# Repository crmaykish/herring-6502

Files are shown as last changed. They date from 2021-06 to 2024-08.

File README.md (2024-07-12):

# Herring 6502

Herring is an 8-bit computer built around the 65C02 CPU. It is designed as a backplane system. The backplane board is passive, providing only power, a reset switch, and system bus headers.
The system bus is exposed as single-row 40-pin female headers using standard 0.1 inch pin pitch.

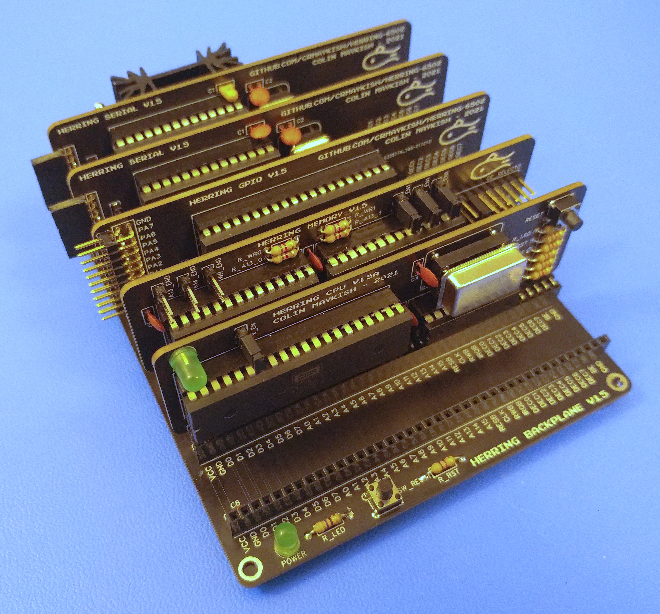
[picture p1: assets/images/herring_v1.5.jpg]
Herring 6502 v1.5


## Hardware

The memory map is set up in the following way:

1. 0x0000 - 0x7FFF: Low RAM (32K)
2. 0x8000 - 0xBFFF: Bankable RAM (16K pages)
3. 0xC000 - 0xDFFF: Memory-mapped I/O (8K)
4. 0xE000 - 0xFFFF: ROM (8K)

Individual component boards are connected to the backplane via the 40-pin system bus. Most of the pins on the bus come directly from the 65C02 plus a few for peripheral support. They are mapped from left to right in the following order:

1. VCC (5v regulated)
2. GND
3. D0
4. D1
5. D2
6. D3
7. D4
8. D5
9. D6
10. D7
11. A0
12. A1
13. A2
14. A3
15. A4
16. A5
17. A6
18. A7
19. A8
20. A9
21. A10
22. A11
23. A12
24. A13
25. A14
26. A15
27. RESB - Reset (Active low)
28. CLK - System clock
29. RWB - Read/write flag (Read = high, Write = low)
30. IRQB - Interrupt request (Active low)
31. DEC0 - Functions as the RAM write-enable pin
32. DEC1 - Peripheral enable
33. DEC2 - Peripheral enable
34. DEC3 - Peripheral enable
35. DEC4 - Peripheral enable
36. DEC5 - Peripheral enable
37. DEC6 - Peripheral enable
38. DEC7 - Peripheral enable
39. BE - Bus Enable (Active high)
40. GND

## Software

Herring currently runs a simple monitor program from ROM that provides the basic peek, poke, jump commands as well as memory clearing and memory dumping. This monitor also functions as a bootloader, allowing new firmware to be copied into RAM from a host PC via serial port. I use a simple program on the PC to transfer firmware: https://github.com/crmaykish/ctt in this way.

All firmware development is done in C and uses the cc65 set of tools.

## Further Reading

See https://hackaday.io/project/181802-herring-6502-computer for project logs and more details on the hardware.

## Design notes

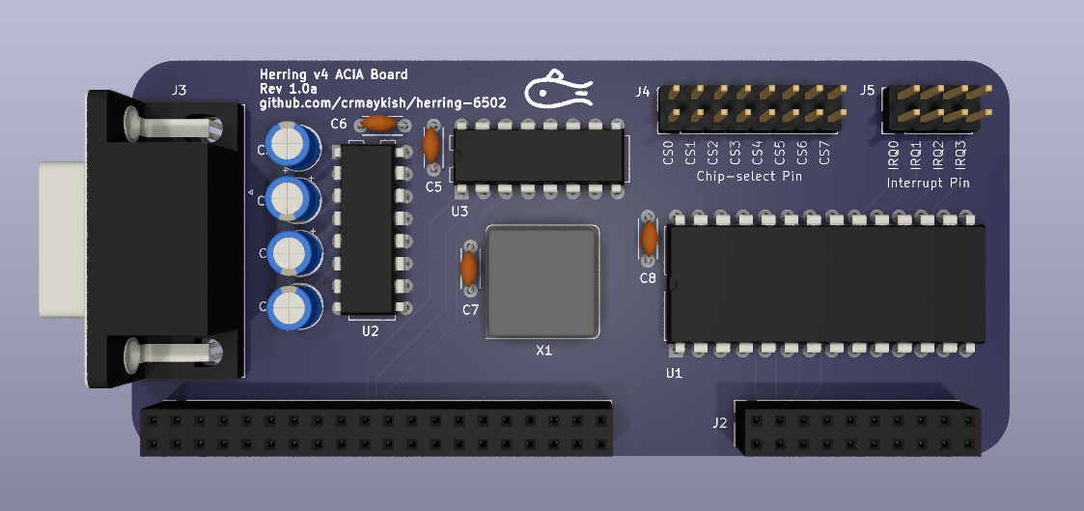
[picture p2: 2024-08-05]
assets/images/herring_v4_acia_rev1a_render.png

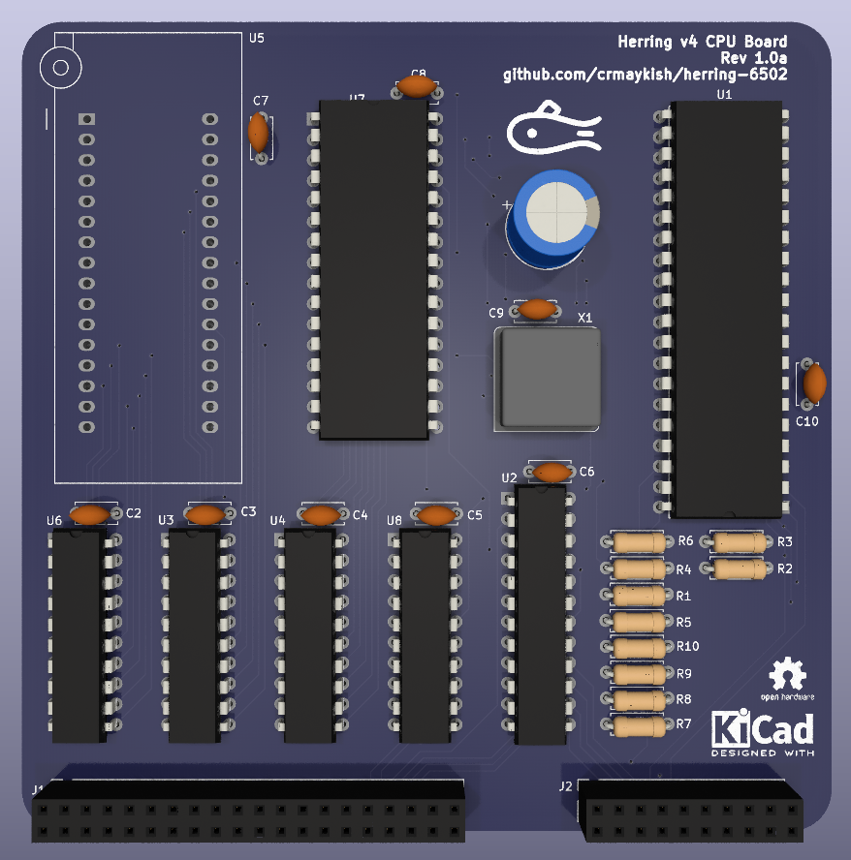
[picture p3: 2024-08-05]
assets/images/herring_v4_cpu_rev1a_render.png

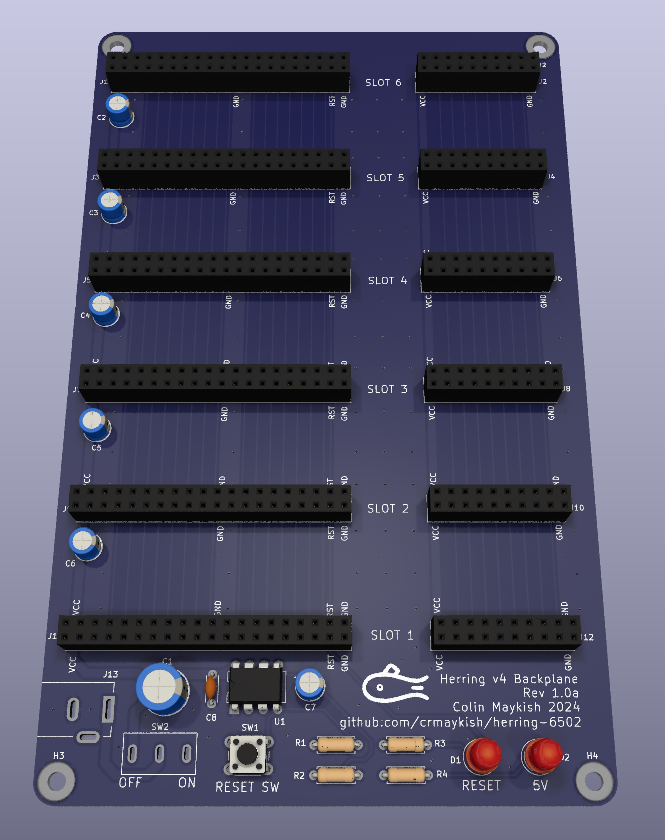
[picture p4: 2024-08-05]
assets/images/herring_v4_backplane_rev1a_render.png

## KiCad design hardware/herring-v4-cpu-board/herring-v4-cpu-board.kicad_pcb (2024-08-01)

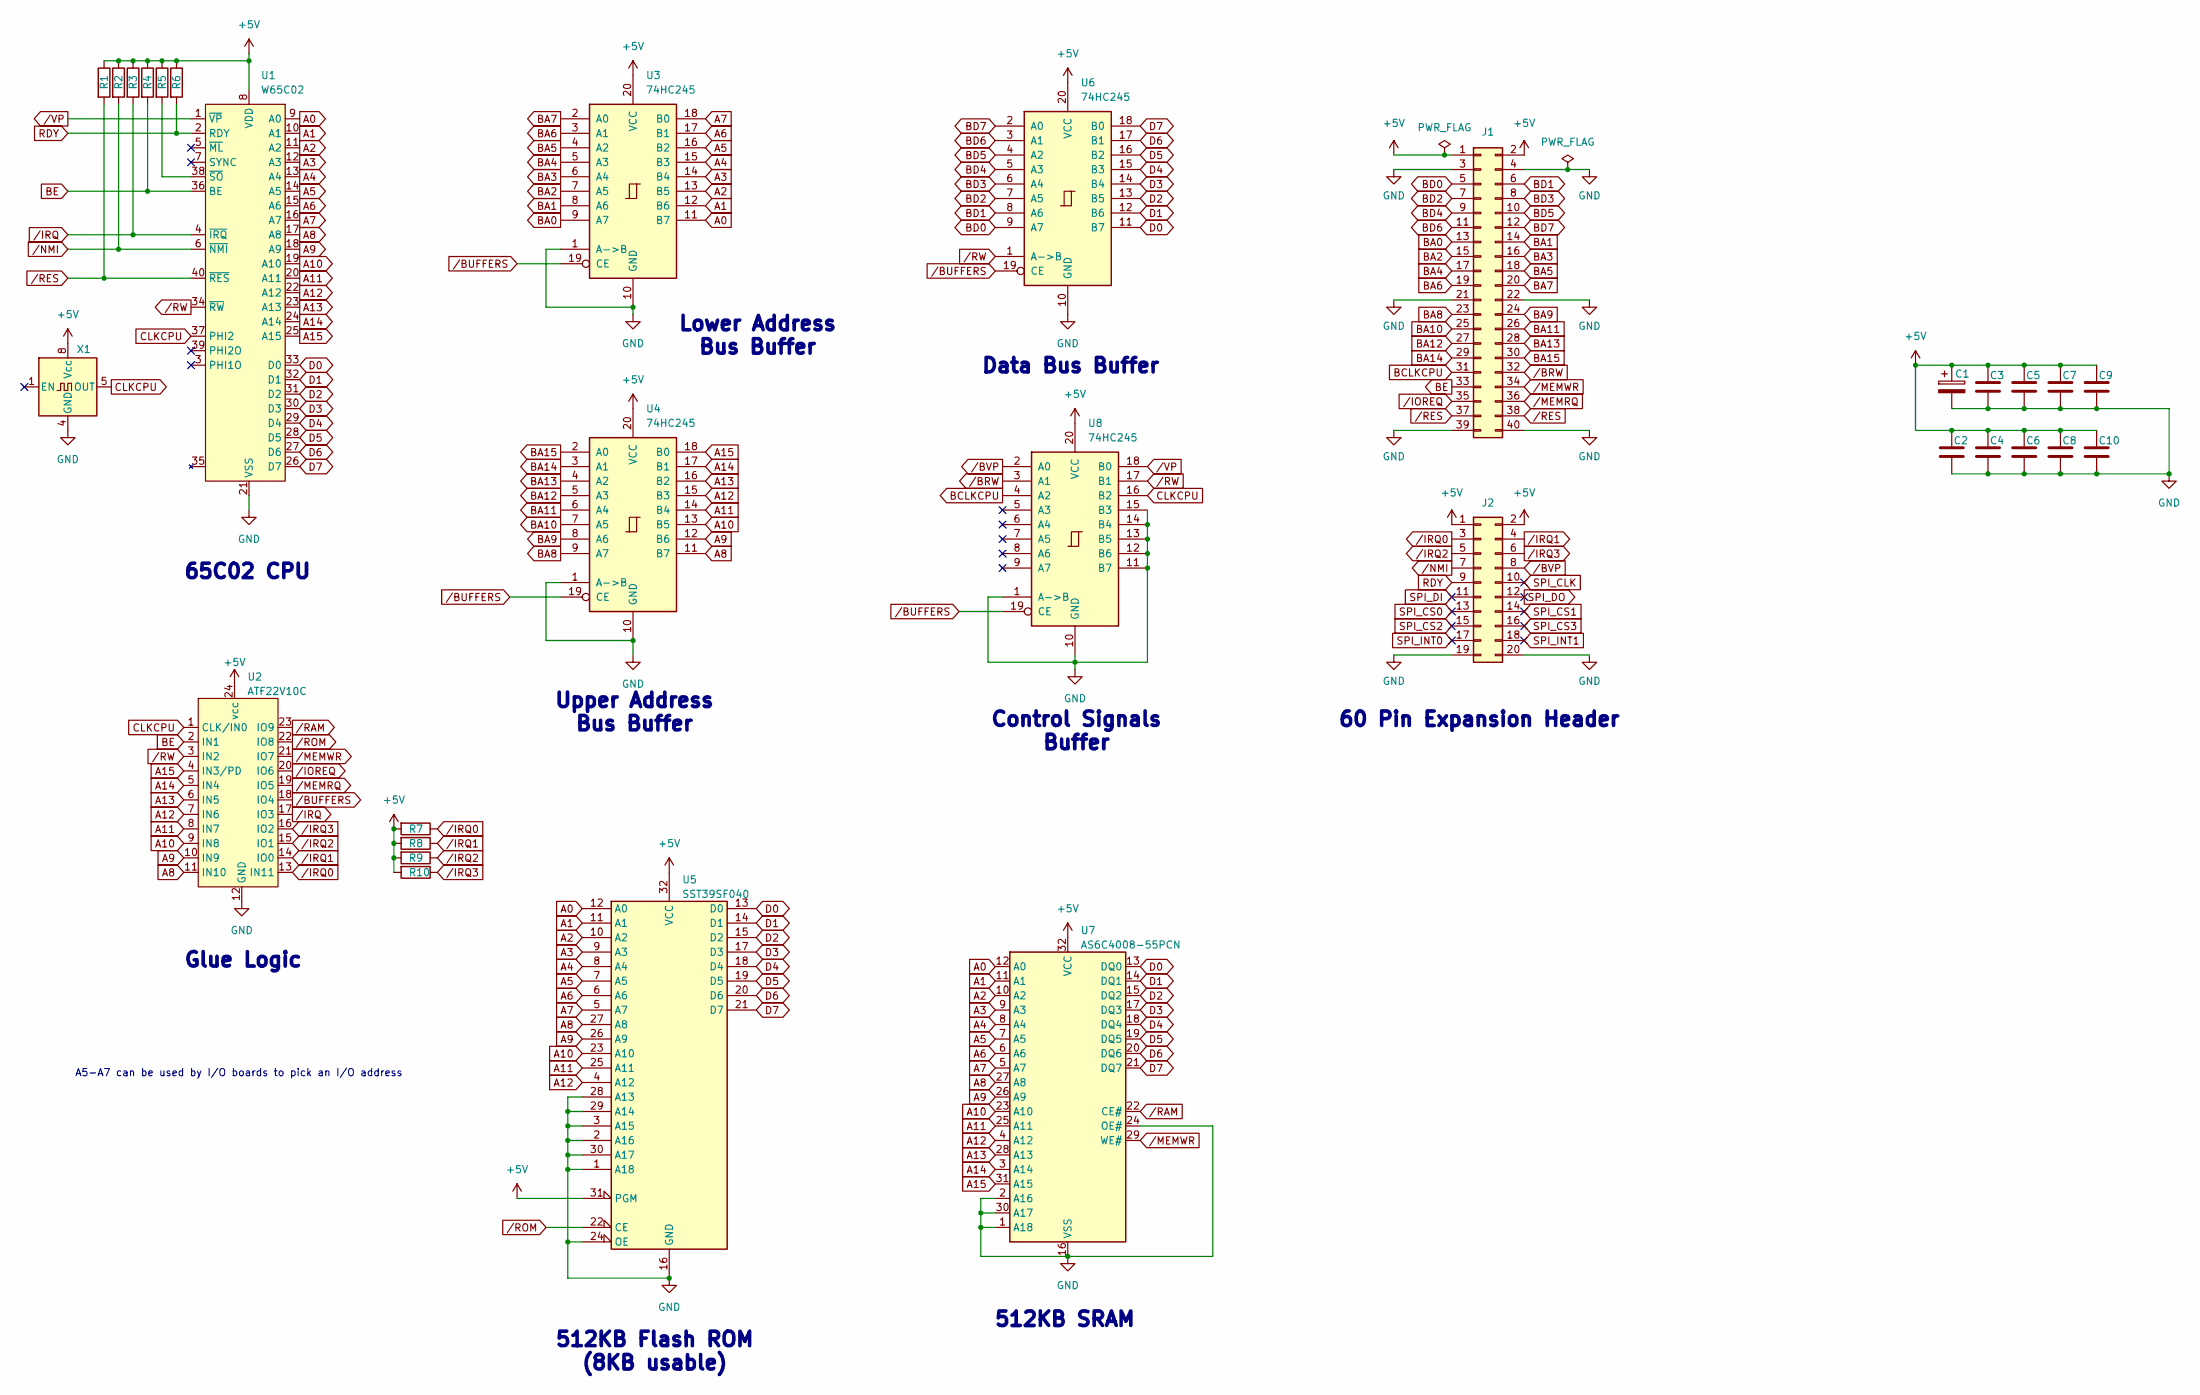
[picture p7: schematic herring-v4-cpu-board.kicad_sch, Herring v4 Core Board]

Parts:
C1: C_Polarized; CP_Radial_D10.0mm_P3.80mm
C2, C3, C4, C5, C6, C7, C8, C9, C10: C; C_Disc_D5.0mm_W2.5mm_P5.00mm
J1: Conn_02x20_Odd_Even; PinSocket_2x20_P2.54mm_Vertical
J2: Conn_02x10_Odd_Even; PinSocket_2x10_P2.54mm_Vertical
R1, R2, R3, R4, R5, R6, R7, R8, R9, R10: R; R_Axial_DIN0207_L6.3mm_D2.5mm_P7.62mm_Horizontal
U1: W65C02; DIP-40_W15.24mm
U2: ATF22V10C; DIP-24_W7.62mm
U3, U4, U6, U8: 74HC245; DIP-20_W7.62mm
U5: SST39SF040; DIP_Socket-32_W11.9_W12.7_W15.24_W17.78_W18.5_3M_232-1285-0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
U7: AS6C4008-55PCN; DIP-32_W15.24mm
X1: CXO_DIP8; Oscillator_DIP-8

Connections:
+5V: C1.1, C2.1, C3.1, C4.1, C5.1, C6.1, C7.1, C8.1, C9.1, C10.1, J1.1, J1.2, J2.1, J2.2, R1.1, R2.1, R3.1, R4.1, R5.1, R6.1, R7.2, R8.2, R9.2, R10.2, U1.8 (VDD), U2.24 (vcc), U3.20 (VCC), U4.20 (VCC), U5.31 (PGM), U5.32 (VCC), U6.20 (VCC), U7.32 (VCC), U8.20 (VCC), X1.8 (Vcc)
A0: U1.9 (A0), U3.11 (B7), U5.12 (A0), U7.12 (A0)
A1: U1.10 (A1), U3.12 (B6), U5.11 (A1), U7.11 (A1)
A2: U1.11 (A2), U3.13 (B5), U5.10 (A2), U7.10 (A2)
A3: U1.12 (A3), U3.14 (B4), U5.9 (A3), U7.9 (A3)
A4: U1.13 (A4), U3.15 (B3), U5.8 (A4), U7.8 (A4)
A5: U1.14 (A5), U3.16 (B2), U5.7 (A5), U7.7 (A5)
A6: U1.15 (A6), U3.17 (B1), U5.6 (A6), U7.6 (A6)
A7: U1.16 (A7), U3.18 (B0), U5.5 (A7), U7.5 (A7)
A8: U1.17 (A8), U2.11 (IN10), U4.11 (B7), U5.27 (A8), U7.27 (A8)
A9: U1.18 (A9), U2.10 (IN9), U4.12 (B6), U5.26 (A9), U7.26 (A9)
A10: U1.19 (A10), U2.9 (IN8), U4.13 (B5), U5.23 (A10), U7.23 (A10)
A11: U1.20 (A11), U2.8 (IN7), U4.14 (B4), U5.25 (A11), U7.25 (A11)
A12: U1.22 (A12), U2.7 (IN6), U4.15 (B3), U5.4 (A12), U7.4 (A12)
A13: U1.23 (A13), U2.6 (IN5), U4.16 (B2), U7.28 (A13)
A14: U1.24 (A14), U2.5 (IN4), U4.17 (B1), U7.3 (A14)
A15: U1.25 (A15), U2.4 (IN3/PD), U4.18 (B0), U7.31 (A15)
BA0: J1.13, U3.9 (A7)
BA1: J1.14, U3.8 (A6)
BA2: J1.15, U3.7 (A5)
BA3: J1.16, U3.6 (A4)
BA4: J1.17, U3.5 (A3)
BA5: J1.18, U3.4 (A2)
BA6: J1.19, U3.3 (A1)
BA7: J1.20, U3.2 (A0)
BA8: J1.23, U4.9 (A7)
BA9: J1.24, U4.8 (A6)
BA10: J1.25, U4.7 (A5)
BA11: J1.26, U4.6 (A4)
BA12: J1.27, U4.5 (A3)
BA13: J1.28, U4.4 (A2)
BA14: J1.29, U4.3 (A1)
BA15: J1.30, U4.2 (A0)
BCLKCPU: J1.31, U8.4 (A2)
BD0: J1.5, U6.9 (A7)
BD1: J1.6, U6.8 (A6)
BD2: J1.7, U6.7 (A5)
BD3: J1.8, U6.6 (A4)
BD4: J1.9, U6.5 (A3)
BD5: J1.10, U6.4 (A2)
BD6: J1.11, U6.3 (A1)
BD7: J1.12, U6.2 (A0)
BE: J1.33, R4.2, U1.36 (BE), U2.2 (IN1)
CLKCPU: U1.37 (PHI2), U2.1 (CLK/IN0), U8.16 (B2), X1.5 (OUT)
D0: U1.33 (D0), U5.13 (D0), U6.11 (B7), U7.13 (DQ0)
D1: U1.32 (D1), U5.14 (D1), U6.12 (B6), U7.14 (DQ1)
D2: U1.31 (D2), U5.15 (D2), U6.13 (B5), U7.15 (DQ2)
D3: U1.30 (D3), U5.17 (D3), U6.14 (B4), U7.17 (DQ3)
D4: U1.29 (D4), U5.18 (D4), U6.15 (B3), U7.18 (DQ4)
D5: U1.28 (D5), U5.19 (D5), U6.16 (B2), U7.19 (DQ5)
D6: U1.27 (D6), U5.20 (D6), U6.17 (B1), U7.20 (DQ6)
D7: U1.26 (D7), U5.21 (D7), U6.18 (B0), U7.21 (DQ7)
GND: C1.2, C2.2, C3.2, C4.2, C5.2, C6.2, C7.2, C8.2, C9.2, C10.2, J1.3, J1.4, J1.21, J1.22, J1.39, J1.40, J2.19, J2.20, U1.21 (VSS), U2.12 (GND), U3.1 (A->B), U3.10 (GND), U4.1 (A->B), U4.10 (GND), U5.1 (A18), U5.2 (A16), U5.3 (A15), U5.16 (GND), U5.24 (OE), U5.28 (A13), U5.29 (A14), U5.30 (A17), U6.10 (GND), U7.1 (A18), U7.2 (A16), U7.16 (VSS), U7.24 (OE#), U7.30 (A17), U8.1 (A->B), U8.10 (GND), U8.11 (B7), U8.12 (B6), U8.13 (B5), U8.14 (B4), U8.15 (B3), X1.4 (GND)
unnamed: R5.2, U1.38 (~SO)
RDY: J2.9, R6.2, U1.2 (RDY)
SPI_CLK: J2.10
SPI_CS0: J2.13
SPI_CS1: J2.14
SPI_CS2: J2.15
SPI_CS3: J2.16
SPI_DI: J2.11
SPI_DO: J2.12
SPI_INT0: J2.17
SPI_INT1: J2.18
/BRW: J1.32, U8.3 (A1)
/BUFFERS: U2.18 (IO4), U3.19 (CE), U4.19 (CE), U6.19 (CE), U8.19 (CE)
/BVP: J2.8, U8.2 (A0)
/IOREQ: J1.35, U2.20 (IO6)
/IRQ: R3.2, U1.4 (~IRQ), U2.17 (IO3)
/IRQ0: J2.3, R7.1, U2.13 (IN11)
/IRQ1: J2.4, R8.1, U2.14 (IO0)
/IRQ2: J2.5, R9.1, U2.15 (IO1)
/IRQ3: J2.6, R10.1, U2.16 (IO2)
/MEMRQ: J1.36, U2.19 (IO5)
/MEMWR: J1.34, U2.21 (IO7), U7.29 (WE#)
/NMI: J2.7, R2.2, U1.6 (~NMI)
/RAM: U2.23 (IO9), U7.22 (CE#)
/RES: J1.37, J1.38, R1.2, U1.40 (~RES)
/ROM: U2.22 (IO8), U5.22 (CE)
/RW: U1.34 (~RW), U2.3 (IN2), U6.1 (A->B), U8.17 (B1)
/VP: U1.1 (~VP), U8.18 (B0)

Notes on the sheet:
65C02 CPU
A5-A7 can be used by I/O boards to pick an I/O address
Glue Logic
Upper Address Bus Buffer
Control Signals Buffer
512KB SRAM
Lower Address Bus Buffer
512KB Flash ROM (8KB usable)
Data Bus Buffer
60 Pin Expansion Header

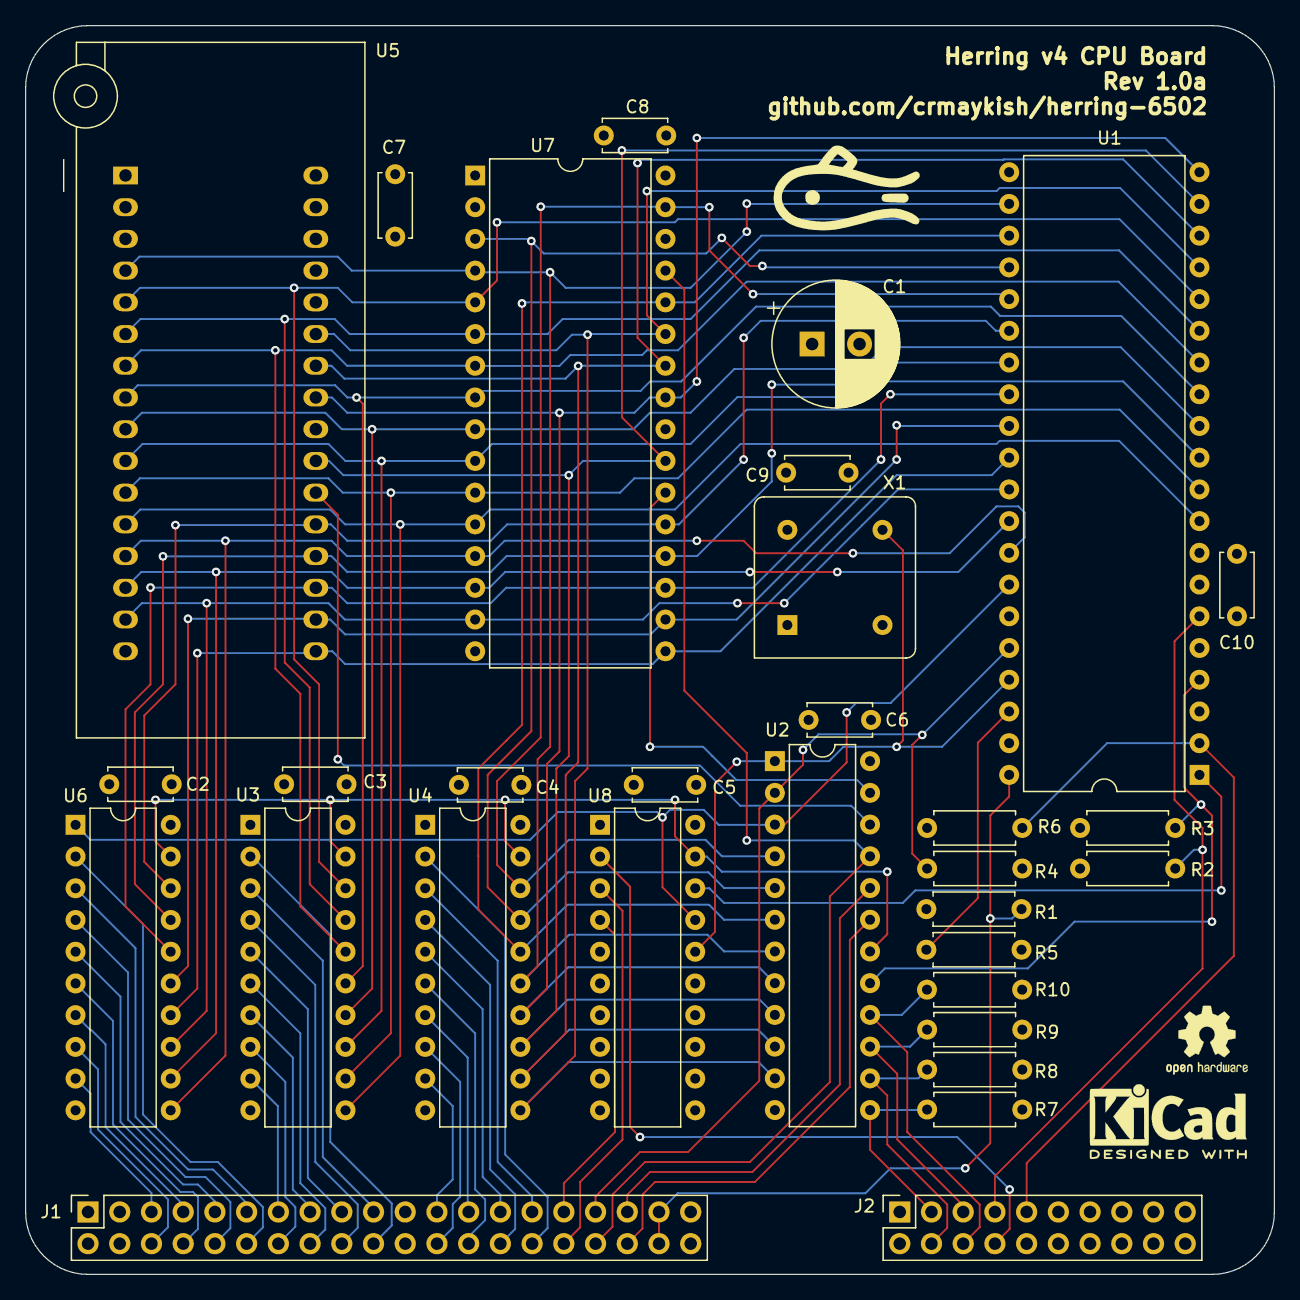
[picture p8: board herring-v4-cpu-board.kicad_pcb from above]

Board: 4 copper layers, 100.0 x 100.0 mm, 31 parts (0 on the bottom side), 72 nets.

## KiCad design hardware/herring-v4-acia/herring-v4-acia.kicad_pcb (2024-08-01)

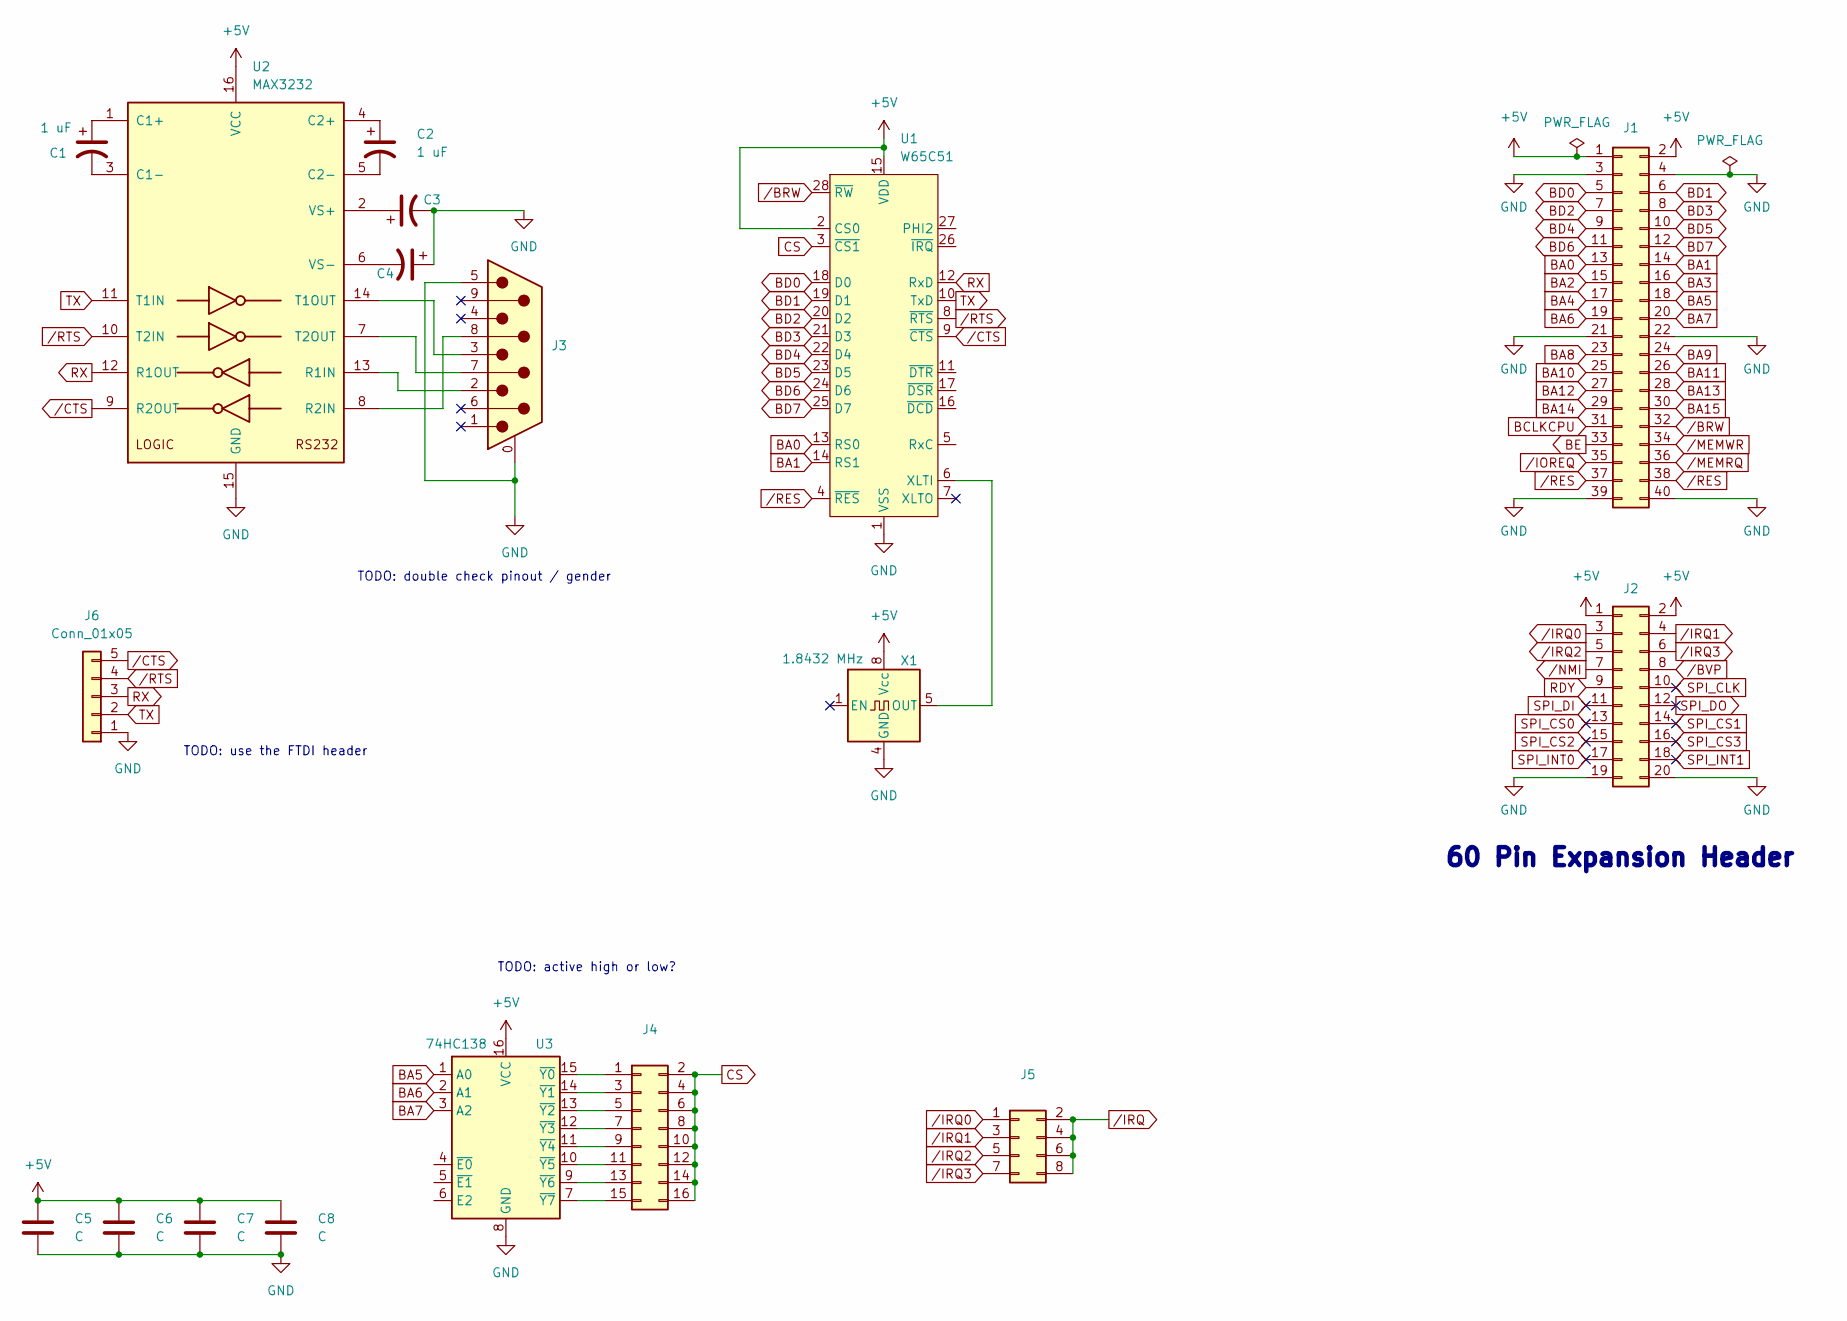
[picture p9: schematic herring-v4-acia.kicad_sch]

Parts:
C1, C2, C3: 1 uF; CP_Radial_D5.0mm_P2.50mm
C4: C_Polarized_US; CP_Radial_D5.0mm_P2.50mm
C5, C6, C7, C8: C; C_Disc_D4.3mm_W1.9mm_P5.00mm
J1: Conn_02x20_Odd_Even; PinSocket_2x20_P2.54mm_Vertical
J2: Conn_02x10_Odd_Even; PinSocket_2x10_P2.54mm_Vertical
J3: DE9_Plug_MountingHoles; DSUB-9_Male_Horizontal_P2.77x2.84mm_EdgePinOffset7.70mm_Hou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
J4: Conn_02x08_Odd_Even; PinHeader_2x08_P2.54mm_Vertical
J5: Conn_02x04_Odd_Even; PinHeader_2x04_P2.54mm_Vertical
J6: Conn_01x05; PinHeader_1x05_P2.54mm_Horizontal
U1: W65C51; DIP-28_W15.24mm
U2: MAX3232; DIP-16_W7.62mm
U3: 74HC138; DIP-16_W7.62mm
X1: 1.8432 MHz; Oscillator_DIP-8

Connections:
+5V: C5.1, C6.1, C7.1, C8.1, J1.1, J1.2, J2.1, J2.2, U1.2 (CS0), U1.15 (VDD), U2.16 (VCC), U3.16 (VCC), X1.8 (Vcc)
BA0: J1.13, U1.13 (RS0)
BA1: J1.14, U1.14 (RS1)
BA2: J1.15
BA3: J1.16
BA4: J1.17
BA5: J1.18, U3.1 (A0)
BA6: J1.19, U3.2 (A1)
BA7: J1.20, U3.3 (A2)
BA8: J1.23
BA9: J1.24
BA10: J1.25
BA11: J1.26
BA12: J1.27
BA13: J1.28
BA14: J1.29
BA15: J1.30
BCLKCPU: J1.31
BD0: J1.5, U1.18 (D0)
BD1: J1.6, U1.19 (D1)
BD2: J1.7, U1.20 (D2)
BD3: J1.8, U1.21 (D3)
BD4: J1.9, U1.22 (D4)
BD5: J1.10, U1.23 (D5)
BD6: J1.11, U1.24 (D6)
BD7: J1.12, U1.25 (D7)
BE: J1.33
CS: J4.2, J4.4, J4.6, J4.8, J4.10, J4.12, J4.14, J4.16, U1.3 (~CS1)
GND: C3.2, C4.1, C5.2, C6.2, C7.2, C8.2, J1.3, J1.4, J1.21, J1.22, J1.39, J1.40, J2.19, J2.20, J3.0 (PAD), J3.5, J6.1, U1.1 (VSS), U2.15 (GND), U3.8 (GND), X1.4 (GND)
unnamed: J4.1, U3.15 (~Y0)
unnamed: J4.3, U3.14 (~Y1)
unnamed: J4.5, U3.13 (~Y2)
unnamed: J4.7, U3.12 (~Y3)
unnamed: J4.9, U3.11 (~Y4)
unnamed: J4.11, U3.10 (~Y5)
unnamed: J4.13, U3.9 (~Y6)
unnamed: J4.15, U3.7 (~Y7)
unnamed: U1.6 (XLTI), X1.5 (OUT)
unnamed: C1.1, U2.1 (C1+)
unnamed: C1.2, U2.3 (C1-)
unnamed: C2.1, U2.4 (C2+)
unnamed: C2.2, U2.5 (C2-)
unnamed: J3.2, U2.13 (R1IN)
unnamed: J3.8, U2.8 (R2IN)
unnamed: J3.3, U2.14 (T1OUT)
unnamed: J3.7, U2.7 (T2OUT)
unnamed: C3.1, U2.2 (VS+)
unnamed: C4.2, U2.6 (VS-)
RDY: J2.9
RX: J6.3, U1.12 (RxD), U2.12 (R1OUT)
SPI_CLK: J2.10
SPI_CS0: J2.13
SPI_CS1: J2.14
SPI_CS2: J2.15
SPI_CS3: J2.16
SPI_DI: J2.11
SPI_DO: J2.12
SPI_INT0: J2.17
SPI_INT1: J2.18
TX: J6.2, U1.10 (TxD), U2.11 (T1IN)
/BRW: J1.32, U1.28 (~RW)
/BVP: J2.8
/CTS: J6.5, U1.9 (~CTS), U2.9 (R2OUT)
/IOREQ: J1.35
/IRQ: J5.2, J5.4, J5.6, J5.8
/IRQ0: J2.3, J5.1
/IRQ1: J2.4, J5.3
/IRQ2: J2.5, J5.5
/IRQ3: J2.6, J5.7
/MEMRQ: J1.36
/MEMWR: J1.34
/NMI: J2.7
/RES: J1.37, J1.38, U1.4 (~RES)
/RTS: J6.4, U1.8 (~RTS), U2.10 (T2IN)

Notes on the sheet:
TODO: use the FTDI header
TODO: active high or low?
TODO: double check pinout / gender
60 Pin Expansion Header

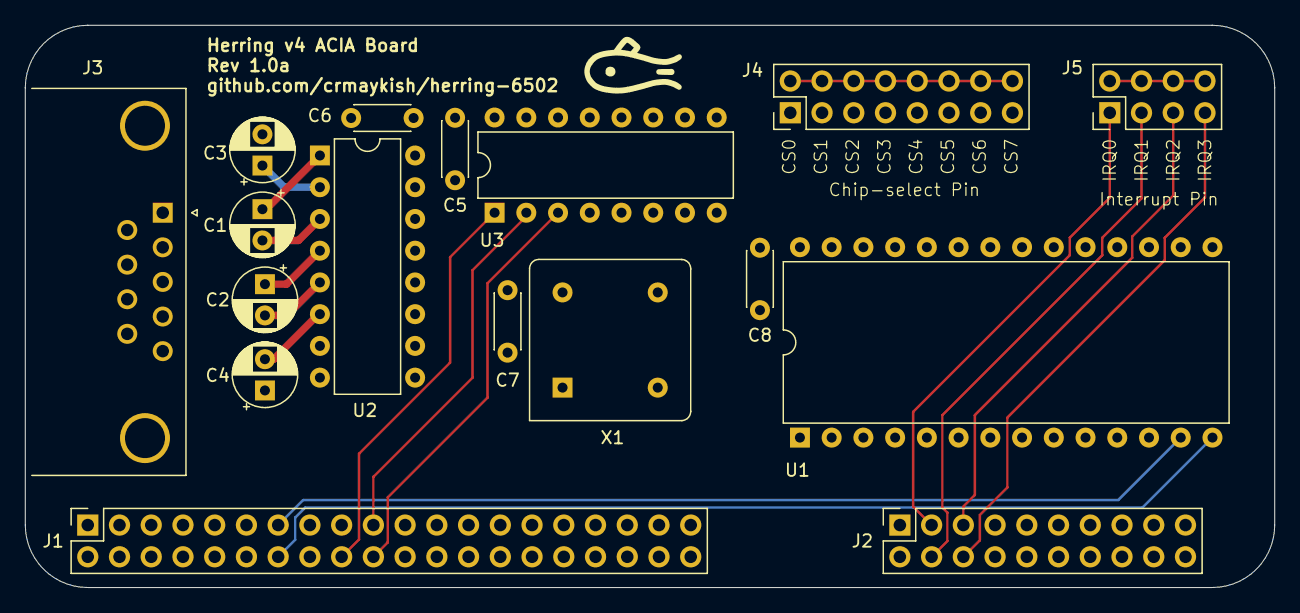
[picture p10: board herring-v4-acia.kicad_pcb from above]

Board: 2 copper layers, 100.0 x 45.0 mm, 17 parts (0 on the bottom side), 46 nets.

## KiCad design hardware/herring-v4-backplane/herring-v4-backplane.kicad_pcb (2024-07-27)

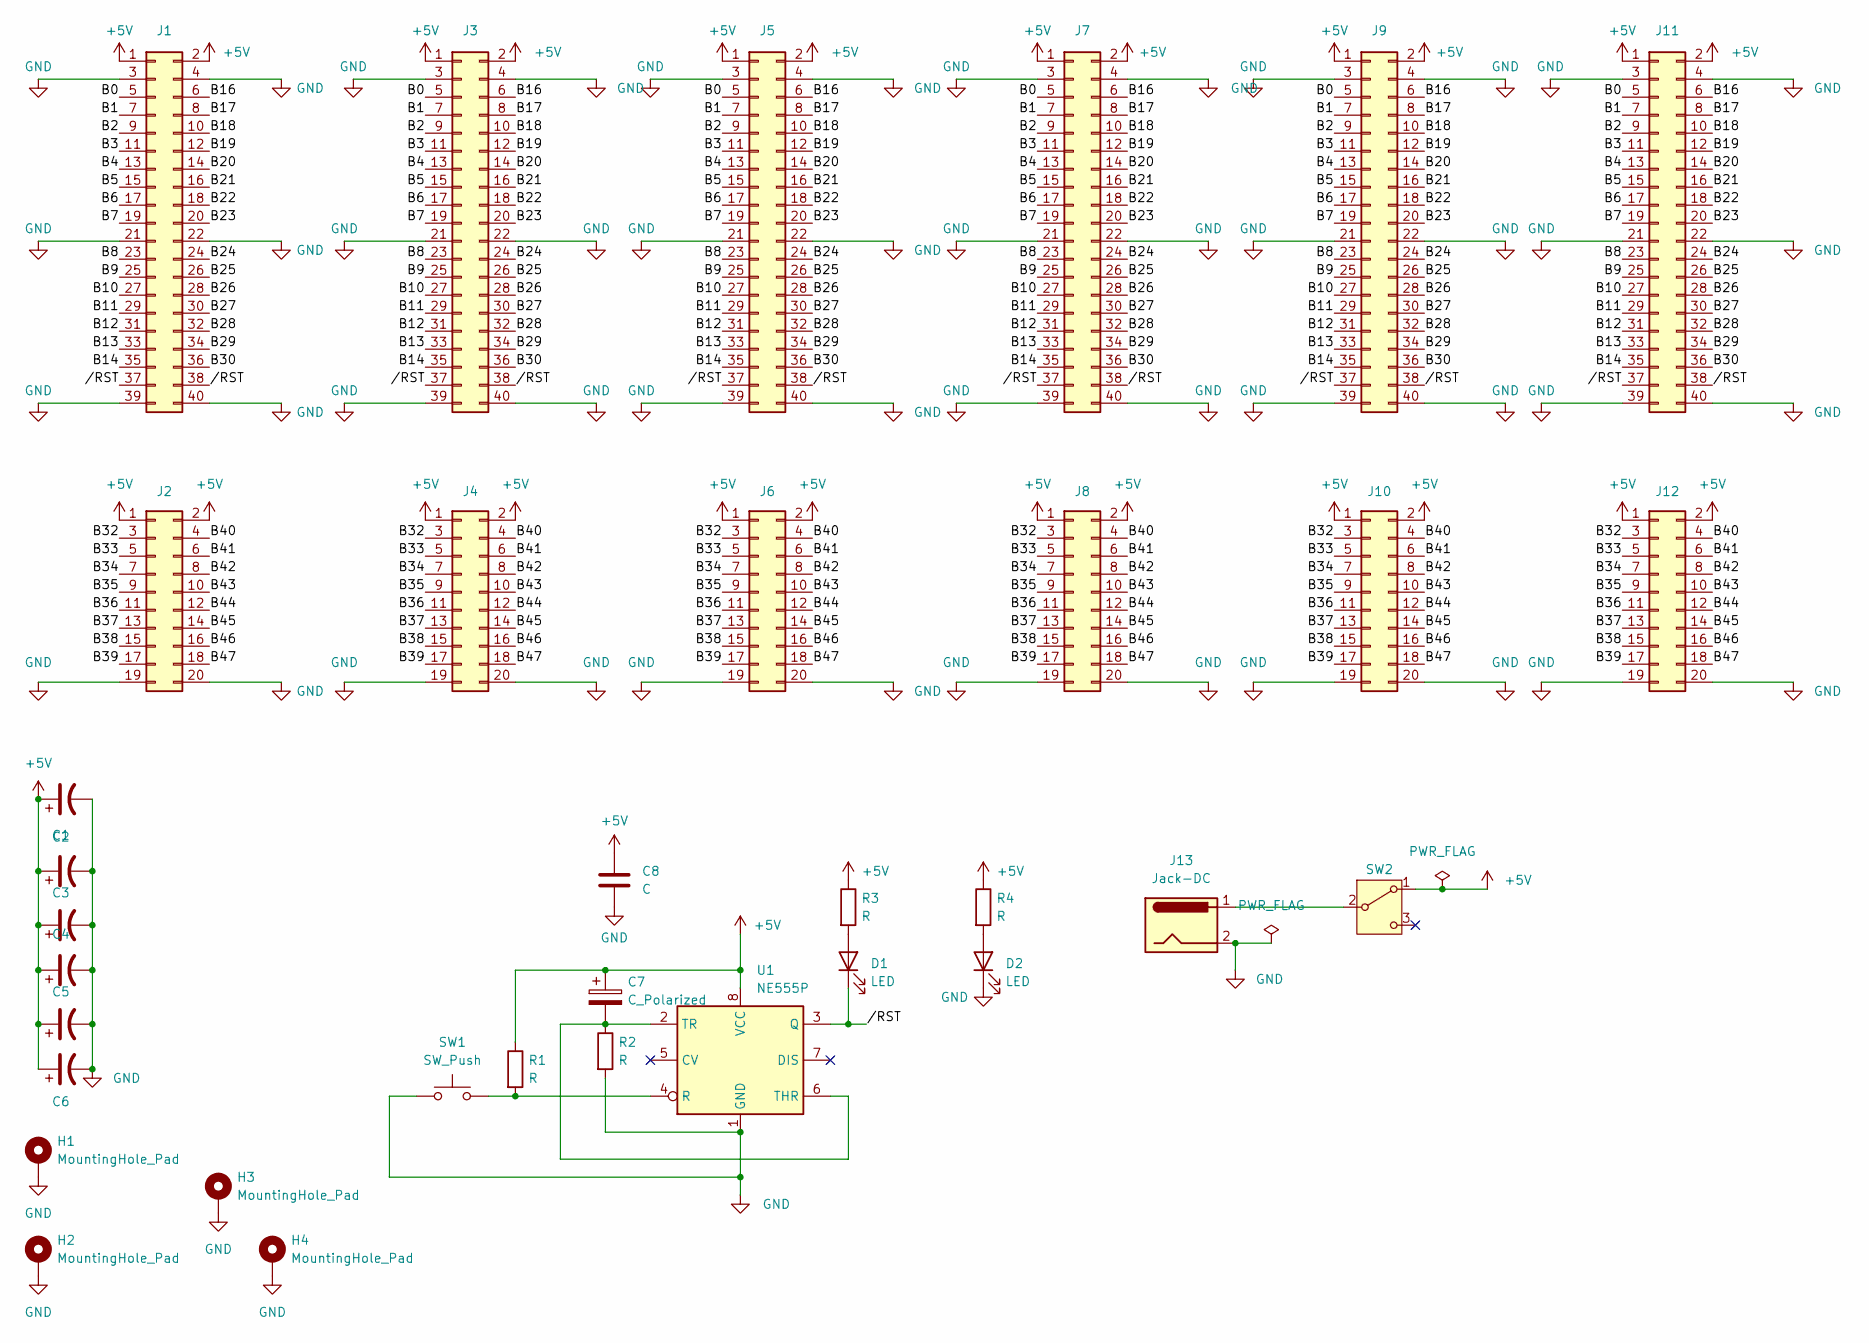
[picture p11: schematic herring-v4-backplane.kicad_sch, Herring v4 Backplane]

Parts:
C1: C_Polarized_US; CP_Radial_D8.0mm_P3.80mm
C2, C3, C4, C5, C6: C_Polarized_US; CP_Radial_D5.0mm_P2.50mm
C7: C_Polarized; CP_Radial_D5.0mm_P2.50mm
C8: C; C_Disc_D4.3mm_W1.9mm_P5.00mm
D1, D2: LED; LED_D5.0mm
H1, H2, H3, H4: MountingHole_Pad; MountingHole_3.2mm_M3_Pad
J1, J3, J5, J7, J9, J11: Conn_02x20_Odd_Even; PinSocket_2x20_P2.54mm_Vertical
J2, J4, J6, J8, J10, J12: Conn_02x10_Odd_Even; PinSocket_2x10_P2.54mm_Vertical
J13: Jack-DC; BarrelJack_Kycon_KLDX-0202-xC_Horizontal
R1, R2, R3, R4: R; R_Axial_DIN0207_L6.3mm_D2.5mm_P7.62mm_Horizontal
SW1: SW_Push; SW_PUSH_6mm_H5mm
SW2: SW_SPDT; SW_Mini_Toggle
U1: NE555P; DIP-8_W7.62mm

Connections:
+5V: C1.1, C2.1, C3.1, C4.1, C5.1, C6.1, C7.1, C8.1, J1.1, J1.2, J2.1, J2.2, J3.1, J3.2, J4.1, J4.2, J5.1, J5.2, J6.1, J6.2, J7.1, J7.2, J8.1, J8.2, J9.1, J9.2, J10.1, J10.2, J11.1, J11.2, J12.1, J12.2, R1.1, R3.1, R4.1, SW2.1 (A), U1.8 (VCC)
/B0: J1.5, J3.5, J5.5, J7.5, J9.5, J11.5
/B1: J1.7, J3.7, J5.7, J7.7, J9.7, J11.7
/B2: J1.9, J3.9, J5.9, J7.9, J9.9, J11.9
/B3: J1.11, J3.11, J5.11, J7.11, J9.11, J11.11
/B4: J1.13, J3.13, J5.13, J7.13, J9.13, J11.13
/B5: J1.15, J3.15, J5.15, J7.15, J9.15, J11.15
/B6: J1.17, J3.17, J5.17, J7.17, J9.17, J11.17
/B7: J1.19, J3.19, J5.19, J7.19, J9.19, J11.19
/B8: J1.23, J3.23, J5.23, J7.23, J9.23, J11.23
/B9: J1.25, J3.25, J5.25, J7.25, J9.25, J11.25
/B10: J1.27, J3.27, J5.27, J7.27, J9.27, J11.27
/B11: J1.29, J3.29, J5.29, J7.29, J9.29, J11.29
/B12: J1.31, J3.31, J5.31, J7.31, J9.31, J11.31
/B13: J1.33, J3.33, J5.33, J7.33, J9.33, J11.33
/B14: J1.35, J3.35, J5.35, J7.35, J9.35, J11.35
/B16: J1.6, J3.6, J5.6, J7.6, J9.6, J11.6
/B17: J1.8, J3.8, J5.8, J7.8, J9.8, J11.8
/B18: J1.10, J3.10, J5.10, J7.10, J9.10, J11.10
/B19: J1.12, J3.12, J5.12, J7.12, J9.12, J11.12
/B20: J1.14, J3.14, J5.14, J7.14, J9.14, J11.14
/B21: J1.16, J3.16, J5.16, J7.16, J9.16, J11.16
/B22: J1.18, J3.18, J5.18, J7.18, J9.18, J11.18
/B23: J1.20, J3.20, J5.20, J7.20, J9.20, J11.20
/B24: J1.24, J3.24, J5.24, J7.24, J9.24, J11.24
/B25: J1.26, J3.26, J5.26, J7.26, J9.26, J11.26
/B26: J1.28, J3.28, J5.28, J7.28, J9.28, J11.28
/B27: J1.30, J3.30, J5.30, J7.30, J9.30, J11.30
/B28: J1.32, J3.32, J5.32, J7.32, J9.32, J11.32
/B29: J1.34, J3.34, J5.34, J7.34, J9.34, J11.34
/B30: J1.36, J3.36, J5.36, J7.36, J9.36, J11.36
/B32: J2.3, J4.3, J6.3, J8.3, J10.3, J12.3
/B33: J2.5, J4.5, J6.5, J8.5, J10.5, J12.5
/B34: J2.7, J4.7, J6.7, J8.7, J10.7, J12.7
/B35: J2.9, J4.9, J6.9, J8.9, J10.9, J12.9
/B36: J2.11, J4.11, J6.11, J8.11, J10.11, J12.11
/B37: J2.13, J4.13, J6.13, J8.13, J10.13, J12.13
/B38: J2.15, J4.15, J6.15, J8.15, J10.15, J12.15
/B39: J2.17, J4.17, J6.17, J8.17, J10.17, J12.17
/B40: J2.4, J4.4, J6.4, J8.4, J10.4, J12.4
/B41: J2.6, J4.6, J6.6, J8.6, J10.6, J12.6
/B42: J2.8, J4.8, J6.8, J8.8, J10.8, J12.8
/B43: J2.10, J4.10, J6.10, J8.10, J10.10, J12.10
/B44: J2.12, J4.12, J6.12, J8.12, J10.12, J12.12
/B45: J2.14, J4.14, J6.14, J8.14, J10.14, J12.14
/B46: J2.16, J4.16, J6.16, J8.16, J10.16, J12.16
/B47: J2.18, J4.18, J6.18, J8.18, J10.18, J12.18
//RST: D1.1 (K), J1.37, J1.38, J3.37, J3.38, J5.37, J5.38, J7.37, J7.38, J9.37, J9.38, J11.37, J11.38, U1.3 (Q)
GND: C1.2, C2.2, C3.2, C4.2, C5.2, C6.2, C8.2, D2.1 (K), H1.1, H2.1, H3.1, H4.1, J1.3, J1.4, J1.21, J1.22, J1.39, J1.40, J2.19, J2.20, J3.3, J3.4, J3.21, J3.22, J3.39, J3.40, J4.19, J4.20, J5.3, J5.4, J5.21, J5.22, J5.39, J5.40, J6.19, J6.20, J7.3, J7.4, J7.21, J7.22, J7.39, J7.40, J8.19, J8.20, J9.3, J9.4, J9.21, J9.22, J9.39, J9.40, J10.19, J10.20, J11.3, J11.4, J11.21, J11.22, J11.39, J11.40, J12.19, J12.20, J13.2, R2.2, SW1.1, U1.1 (GND)
unnamed: D1.2 (A), R3.2
unnamed: D2.2 (A), R4.2
unnamed: J13.1, SW2.2 (B)
unnamed: R1.2, SW1.2, U1.4 (R)
unnamed: C7.2, R2.1, U1.2 (TR), U1.6 (THR)

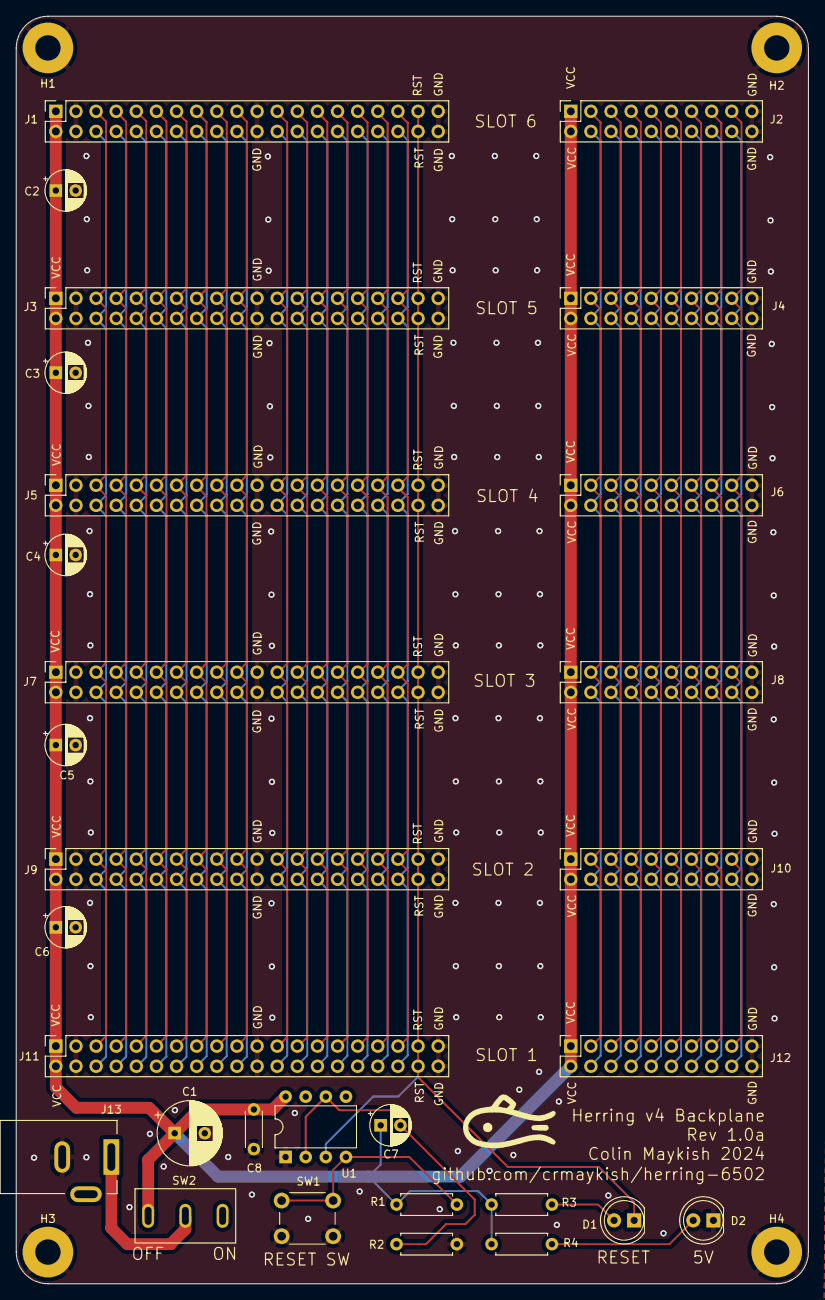
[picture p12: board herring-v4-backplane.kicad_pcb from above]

Board: 2 copper layers, 100.0 x 160.0 mm, 34 parts (0 on the bottom side), 54 nets.

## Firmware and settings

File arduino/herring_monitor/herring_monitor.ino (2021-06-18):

/**
 * @file herring_monitor.ino
 * @author Colin Maykish
 * @brief Serial Monitor for the Herring 6502 computer system
 * Reads the data and address buses and controls the clock and reset pins for the 6502
 * 
 * @date 2021-06-11
 * 
 * @copyright Copyright (c) 2021
 */

// Pin Definitions
#define PORT_ADDR_HIGH PORTB
#define PORT_ADDR_LOW PORTA
#define PORT_DATA PORTC

#define PIN_ADDR_HIGH PINB
#define PIN_ADDR_LOW PINA
#define PIN_DATA PINC

#define DDR_ADDR_HIGH DDRB
#define DDR_ADDR_LOW DDRA
#define DDR_DATA DDRC

#define RST 12
#define CLK 13
#define RW 14

// WARNING: At some point, the serial monitor will no longer be able to keep up with the clock speed
// and will start missing changes on the buses

#define DEFAULT_CLOCK_SPEED_HZ 40

#define SERIAL_BAUDRATE 250000

typedef struct
{
    bool Running;
    bool ReadWrite;
    uint16_t AddressBus;
    uint16_t PrevAddressBus;
    uint8_t DataBus;
    uint8_t PrevDataBus;
    unsigned int ClockSpeed;
} CPU_6502_t;

static CPU_6502_t cpu = {
    .Running = true,
    .ReadWrite = false,
    .AddressBus = 0x0000,
    .PrevAddressBus = 0x0000,
    .DataBus = 0x00,
    .PrevDataBus = 0x00,
    .ClockSpeed = DEFAULT_CLOCK_SPEED_HZ};

uint8_t reverse_bits(uint8_t b)
{
    return ((b & 0b1) << 7) |
           ((b & 0b10) << 5) |
           ((b & 0b100) << 3) |
           ((b & 0b1000) << 1) |
           ((b & 0b10000) >> 1) |
           ((b & 0b100000) >> 3) |
           ((b & 0b1000000) >> 5) |
           ((b & 0b10000000) >> 7);
}

static char log_message[64];

void log(String s)
{
    Serial.println(s);
}

void dump_cpu_state()
{
    sprintf(log_message, "%04X | %02X | %d", cpu.AddressBus, cpu.DataBus, cpu.ReadWrite);
    log(log_message);
}

void cpu_cycle(int count)
{
    for (int i = 0; i < count; i++)
    {
        digitalWrite(CLK, LOW);
        delay(10);
        digitalWrite(CLK, HIGH);
        delay(10);
    }

    cpu.PrevAddressBus = cpu.AddressBus;
    cpu.PrevDataBus = cpu.DataBus;

    // Read the CPU buses
    cpu.AddressBus = (reverse_bits(PIN_ADDR_HIGH) << 8) + reverse_bits(PIN_ADDR_LOW);
    cpu.DataBus = reverse_bits(PIN_DATA);
    cpu.ReadWrite = digitalRead(RW);
}

void cpu_reset()
{
    log("Resetting 65C02...");
    digitalWrite(RST, LOW);
    delay(100);
    cpu_cycle(1);
    digitalWrite(RST, HIGH);
    delay(100);
}

void setup()
{
    // Control Pins
    pinMode(CLK, OUTPUT);
    pinMode(RST, OUTPUT);
    pinMode(RW, INPUT);

    // Set address and data buses as inputs
    DDR_ADDR_HIGH |= 0x00;
    DDR_ADDR_LOW |= 0x00;
    DDR_DATA |= 0x00;

    pinMode(RST, OUTPUT);
    pinMode(CLK, OUTPUT);
    pinMode(RW, INPUT);

    // Start serial monitor
    Serial.begin(SERIAL_BAUDRATE);

    tone(CLK, cpu.ClockSpeed);
    cpu_reset();
}

void loop()
{
    if (Serial.available() > 0)
    {
        String command = Serial.readStringUntil('\n');

        if (command.equals("RUN"))
        {
            log("Run");
            cpu.Running = true;
            tone(CLK, cpu.ClockSpeed);
        }
        else if (command.equals("STOP"))
        {
            log("Stop");
            cpu.Running = false;
            noTone(CLK);
            digitalWrite(CLK, HIGH);
        }
        else if (command.equals("RESET"))
        {
            cpu_reset();
        }
        else if (command.equals("SLOW"))
        {
            cpu.ClockSpeed = 40;
            log("Clock set to 40Hz");
        }
        else if (command.equals("MEDIUM"))
        {
            cpu.ClockSpeed = 500;
            log("Clock set to 500Hz");
        }
        else if (command.equals("FAST"))
        {
            cpu.ClockSpeed = 20000;
            log("Clock set to 20kHz");
        }
        else if (command.equals("TURBO"))
        {
            cpu.ClockSpeed = 100000;
            log("Clock set to 100kHz");
        }
        else if (command.equals("MAX"))
        {
            cpu.ClockSpeed = 500000;
            log("Clock set to 500kHz");
        }
        else if (!cpu.Running)
        {
            cpu_cycle(1);

            // Print the buses after each cycle when single-stepping
            dump_cpu_state();
        }
    }

    if (cpu.Running)
    {
        cpu_cycle(0);

        if (cpu.AddressBus != cpu.PrevAddressBus || cpu.DataBus != cpu.PrevDataBus)
        {
            // Only print the buses if something has changed
            dump_cpu_state();
        }
    }
}

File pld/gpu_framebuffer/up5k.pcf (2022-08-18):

set_io --warn-no-port VGA_RED 28
set_io --warn-no-port VGA_GREEN 38
set_io --warn-no-port VGA_BLUE 42
set_io --warn-no-port VGA_HSYNC 43
set_io --warn-no-port VGA_VSYNC 36

set_io --warn-no-port DATA[0] 2
set_io --warn-no-port DATA[1] 46
set_io --warn-no-port DATA[2] 47
set_io --warn-no-port DATA[3] 45
set_io --warn-no-port DATA[4] 48
set_io --warn-no-port DATA[5] 3
set_io --warn-no-port DATA[6] 4

set_io --warn-no-port ADDR[0] 44
set_io --warn-no-port ADDR[1] 6
set_io --warn-no-port ADDR[2] 9
set_io --warn-no-port ADDR[3] 11
set_io --warn-no-port ADDR[4] 18
set_io --warn-no-port ADDR[5] 19
set_io --warn-no-port ADDR[6] 13
set_io --warn-no-port ADDR[7] 21
set_io --warn-no-port ADDR[8] 12
set_io --warn-no-port ADDR[9] 10
set_io --warn-no-port ADDR[10] 23
set_io --warn-no-port ADDR[11] 25
set_io --warn-no-port ADDR[12] 26
set_io --warn-no-port ADDR[13] 27
set_io --warn-no-port ADDR[14] 32

set_io --warn-no-port RW 34
set_io --warn-no-port CE 37
set_io --warn-no-port CLK_CPU 31

set_io --warn-no-port CLK 20

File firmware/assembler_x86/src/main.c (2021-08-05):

#include <stdio.h>
#include <stdlib.h>
#include "herring.h"
#include "assembler.h"

static char source[] = "lda #$FF\r\nsta $C002\r\nsta $C003\r\n";

void print_hex(word w)
{
    printf("%02X", w);
}

int main(int argc, char *argv[])
{
    char source[4096] = {0};
    byte machine_code[1024] = {0};

    FILE *source_file = fopen(argv[1], "r");
    FILE *bin_file = fopen(argv[2], "w+");
    printf("Reading source file...\r\n");

    int index = 0;

    char c = 0;

    while (c != EOF)
    {
        c = fgetc(source_file);
        source[index] = c;
        index++;
    }

    fclose(source_file);

    printf("Assembling source: \r\n");
    printf(source);

    word size = assemble(source, machine_code);

    printf("Machine code: \r\n");
    for (int i = 0; i < size; i++)
    {
        print_hex(machine_code[i]);
        printf(" ");

        fputc(machine_code[i], bin_file);
    }

    printf("\r\n");

    fclose(bin_file);

    return 0;
}

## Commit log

2021-06-08 Added Arduino monitor sketch and LED panel controller
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2021-06-12 monitor working with cpu daughter board
2021-06-13 RAM test assembly code running correctly
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2021-06-16 Port A on the VIA board hooked up and working correctly
2021-06-17 prep monitor program for uart emulation
2021-06-17 fake uart sort of working, not worth the effort
2021-06-17 Really basic UART writing is working with some hacks
2021-06-17 Emulated UART only works up to a few kHz CPU speed before it can no longer keep up
    [herring_monitor.ino]
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2021-06-18 working on C
    [firmware.cfg]
2021-06-22 watching all control pins
    [firmware.cfg]
2021-07-02 fixed asm demos for board 1
2021-07-04 Converted to CC65 assembler
    [herring.cfg]
2021-07-04 C code compiling
    [herring.cfg]
2021-07-05 VIA demo with CA65
    [herring.cfg]
2021-07-05 via demo in C compiles and runs!
    [herring.cfg]
2021-07-08 print and goto commands in BASIC are implemented
2021-07-09 refactored for new memory board
    [herring.cfg]
2021-07-10 everything sucks
    [herring.cfg]
2021-07-12 Code loaded into RAM and running
    [programs.cfg]
2021-07-12 Installed clock board, running loader at 1MHz
    [programs.cfg]
2021-07-12 cc65 config for RAM loaded programs
    [programs.cfg]
2021-07-12 16-bit counter program on the VIA LEDs
2021-07-12 memdump style command running
    [programs.cfg]
2021-07-14 LED Matrix interface stub
2021-07-15 Added poke and reset, reload commands to sysmon
    [herring.h]
2021-07-15 Added ASCII printout to memdump
2021-07-15 proof of concept LED matrix connection with VIA
2021-07-16 SPI not working
2021-07-21 SPI proof of concept
2021-07-22 SPI work and cleanup
2021-07-24 Board B proof of concept in C
    [board_b.cfg]
2021-07-24 Fixed interrupt handling for Board B
2021-07-25 Cleaned up print function
2021-07-25 Refactored serial is working at low speed, not 1MHz
    [loader.cfg, program.cfg]
2021-07-25 Serial port ASM is working well
    [loader.cfg]
2021-07-25 Cleanup old code
    [board_b.cfg, programs.cfg]
2021-07-26 build scripts for loader and ram programs
    [loader.cfg, program.cfg]
2021-07-28 Back to booting with a C config
    [loader.cfg]
2021-07-28 ACIA print function in ASM
2021-07-31 Serial loader working again.. WDC chips are terrible
    [loader.cfg]
2021-07-31 Returning to loader when RAM programs exit
    [loader.cfg, program.cfg]
2021-08-03 First self-assembled code runs
2021-08-05 LCD module handles text wrapping and resetting correctly
    [main.c]
2021-08-05 Handle carriage return in lcd_write()
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2021-08-05 cross assembler accepts input and output filenames
2021-08-05 Assembler works on Herring
2021-08-09 fixed crash from EOF character in source
    [main.c]
2021-08-09 remove printfs from assembler
2021-08-18 loop primes
    [program.cfg]
2021-08-22 Serial demo with memulator installed
    [zero.cfg]
2021-08-25 Add new RAM to Zero config
    [zero.cfg]
2021-08-27 Herring Zero test assembly
2021-08-27 simplified ROM emulation
    [zero.cfg]
2021-08-28 Building C program for Zero
    [loader.cfg, program.cfg, zero.cfg]
2021-09-01 booting from ROM on 3.3v and 5v boards
    [loader.cfg]
2021-09-02 Added run-from-ram config and load command to serial monitor
    [ram.cfg]
2021-09-10 proof of concept GPIO latch working on Upduino board
2021-09-10 Add low voltage ROM and increase CPU speed to 6.25 MHz
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2021-11-17 fixed font and framebuffer loading
2021-11-18 bigger framebuffer cells working with new version of apio
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2021-11-22 Building Pi Pico code in a Docker container
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2021-12-01 3.3v board running at 8.33 MHz, PHI2 and PHI20 controlled by FPGA
2021-12-05 Simpler structure for the firmware code
    [rom.cfg]
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2021-12-11 Cleaned up config for RAM based programs
    [ram.cfg, rom.cfg]
2021-12-23 Proof of concept listing files and printing contents over serial port
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2022-08-21 Moved SD card circuit to dedicated VIA board
2022-10-18 Start KiCAD project for Herring v4
    [herring_sbc.kicad_pcb, herring_sbc.sch]
2022-10-18 Add 16C550 symbol
    [herring_sbc.sch]
2022-10-19 Created KiCAD symbols for core components
    [herring_sbc.kicad_pcb, herring_sbc.sch, herring_v4.kicad_pcb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]
2022-11-03 Replace 65C51 with 16C550
    [herring.h]
2022-11-03 Add 16C550 to schematic
    [herring_v4.kicad_pcb, herring_v4.kicad_sch]
2022-11-03 Strip down CPU board schematic
    [herring_v4.kicad_pcb, herring_v4.kicad_sch]
2024-06-03 Dust off the single PCB version of Herring and boot it back up
2024-07-12 Core board and backplane for v4 routed
    [herring-v4-backplane.kicad_pcb, herring-v4-backplane.kicad_sch, herring-v4-cpu-board.kicad_pcb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]
2024-07-12 stubbed out I/O board
    [herring-v4-io-board.kicad_pcb, herring-v4-io-board.kicad_sch]
2024-07-13 herring v4 backplane routed
    [herring-v4-backplane.kicad_pcb, herring-v4-backplane.kicad_sch]
2024-07-13 Proto board is mostly designed
    [herring-v4-io-board.kicad_pcb, herring-v4-io-board.kicad_sch, herring-v4-proto-board.kicad_pcb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]
2024-07-14 Add logos to backplane
    [herring-v4-backplane.kicad_pcb]
2024-07-27 Herring v4 backplane gerber files
    [herring-v4-backplane.kicad_pcb, herring-v4-backplane.kicad_sch, herring-v4-proto-board.kicad_pcb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]
2024-07-28 CPU board schematic mostly done, started routing
    [herring-v4-cpu-board.kicad_pcb, herring-v4-cpu-board.kicad_sch]
2024-07-30 Routed buffers and expansion header
    [herring-v4-cpu-board.kicad_pcb, herring-v4-cpu-board.kicad_sch]
2024-07-30 v4 CPU board fully routed, needs cleanup
    [herring-v4-cpu-board.kicad_pcb, herring-v4-cpu-board.kicad_sch]
2024-08-01 Stub out v4 ACIA board
    [herring-v4-acia.kicad_pcb, herring-v4-acia.kicad_sch, herring-v4-cpu-board.kicad_pcb]
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
